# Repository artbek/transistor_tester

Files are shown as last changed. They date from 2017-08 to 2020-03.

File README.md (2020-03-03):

Transistor tester (BJT NPN pin identifier)
==========================================

The little gadget displays: `C`ollector, `b`ase, `E`mitter ... and an animation of slinky if no BJT can be detected.

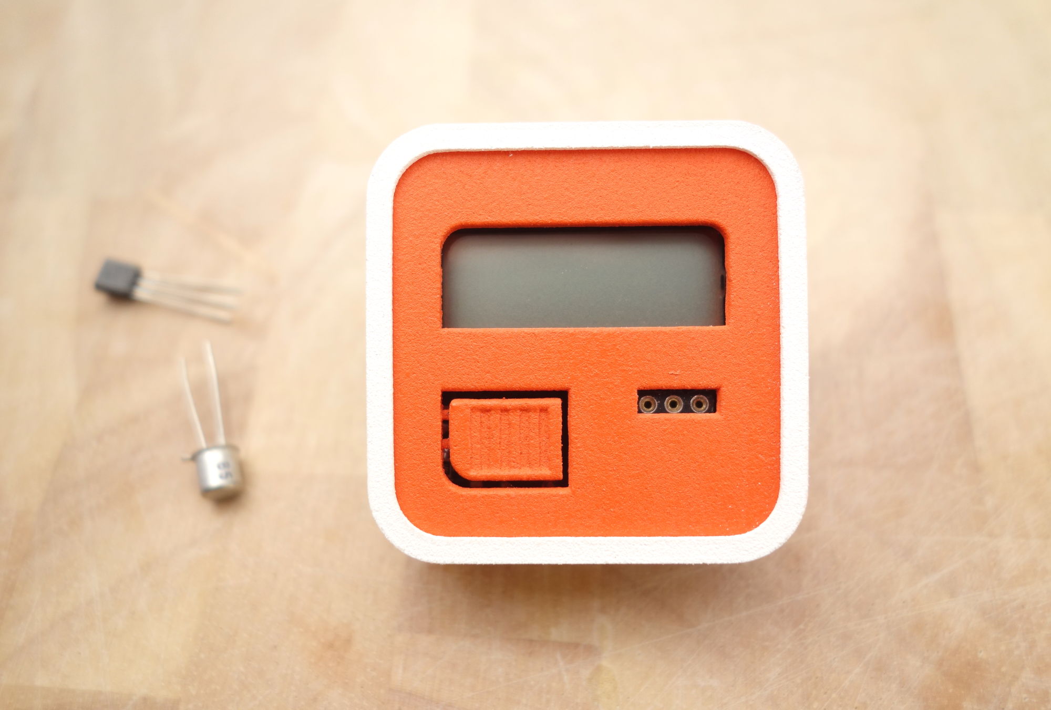
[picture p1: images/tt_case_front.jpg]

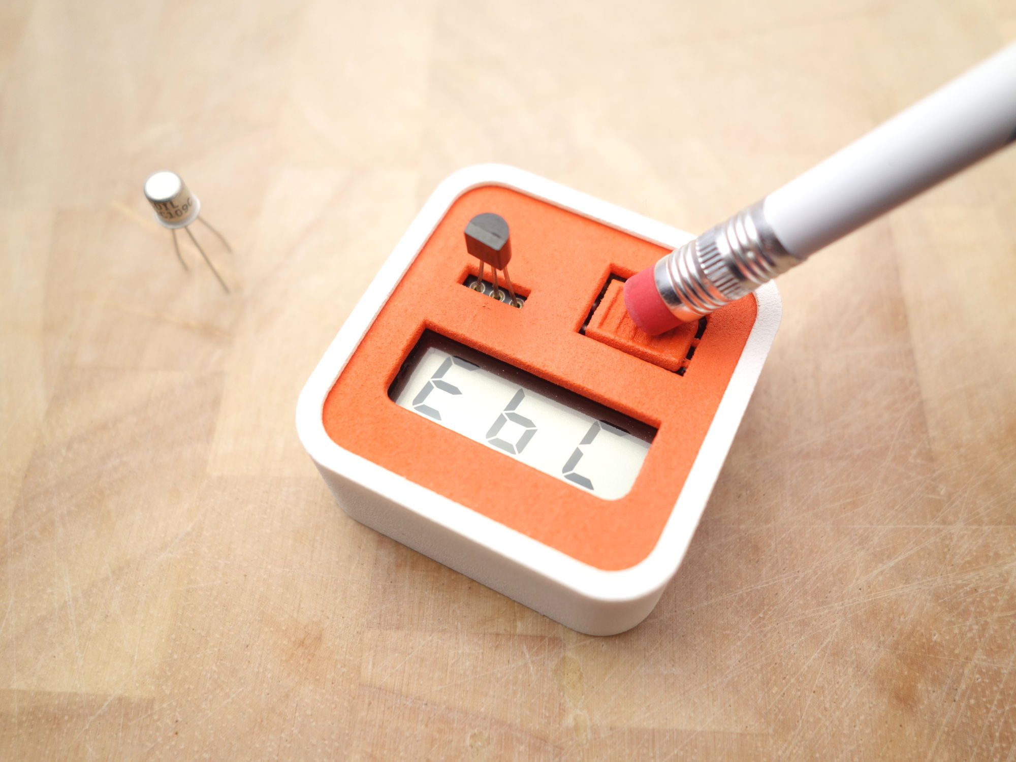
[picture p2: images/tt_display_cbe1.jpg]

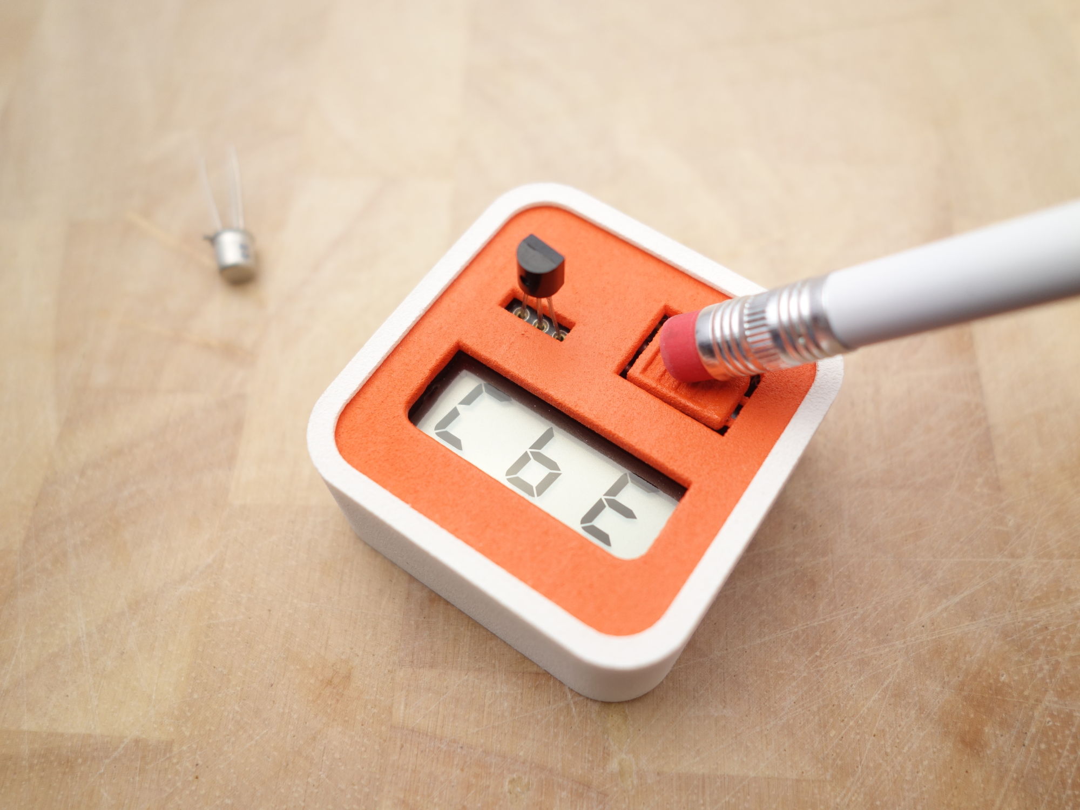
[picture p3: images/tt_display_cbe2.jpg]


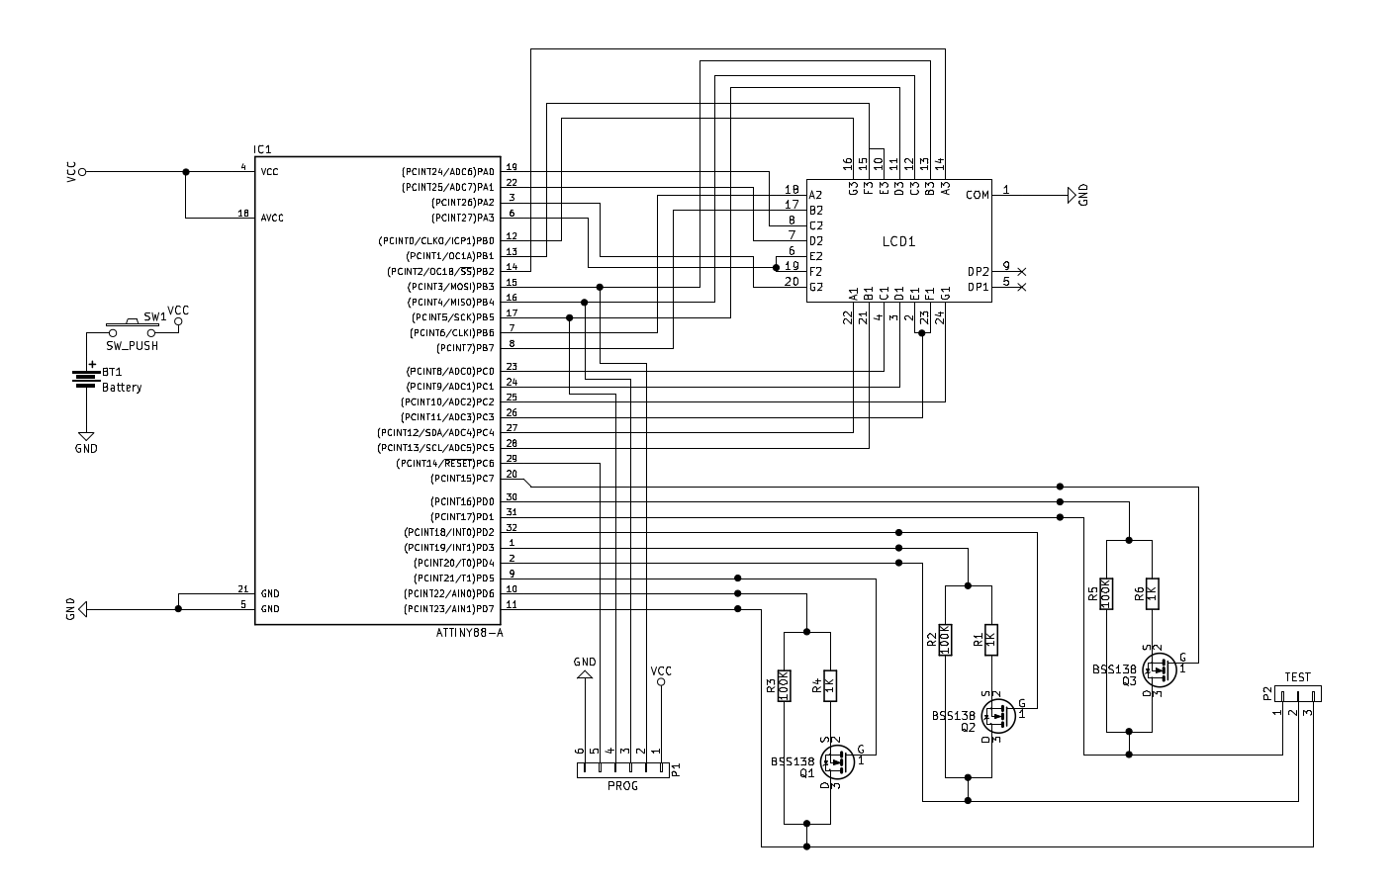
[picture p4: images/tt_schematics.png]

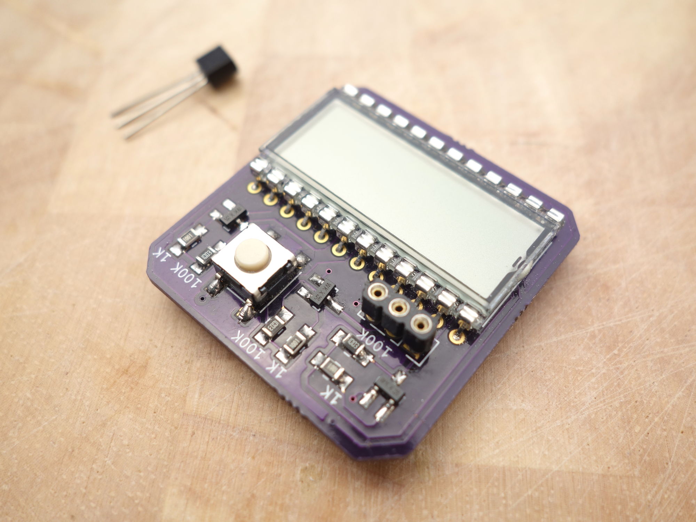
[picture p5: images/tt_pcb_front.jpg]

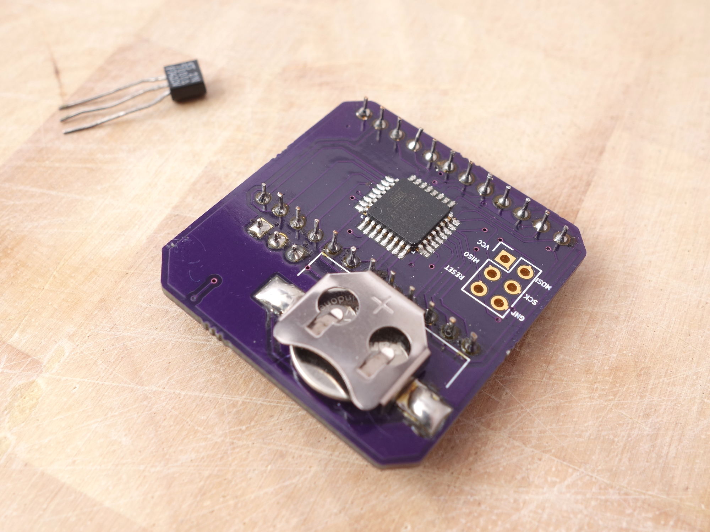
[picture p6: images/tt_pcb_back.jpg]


3D printed and spray-painted case.

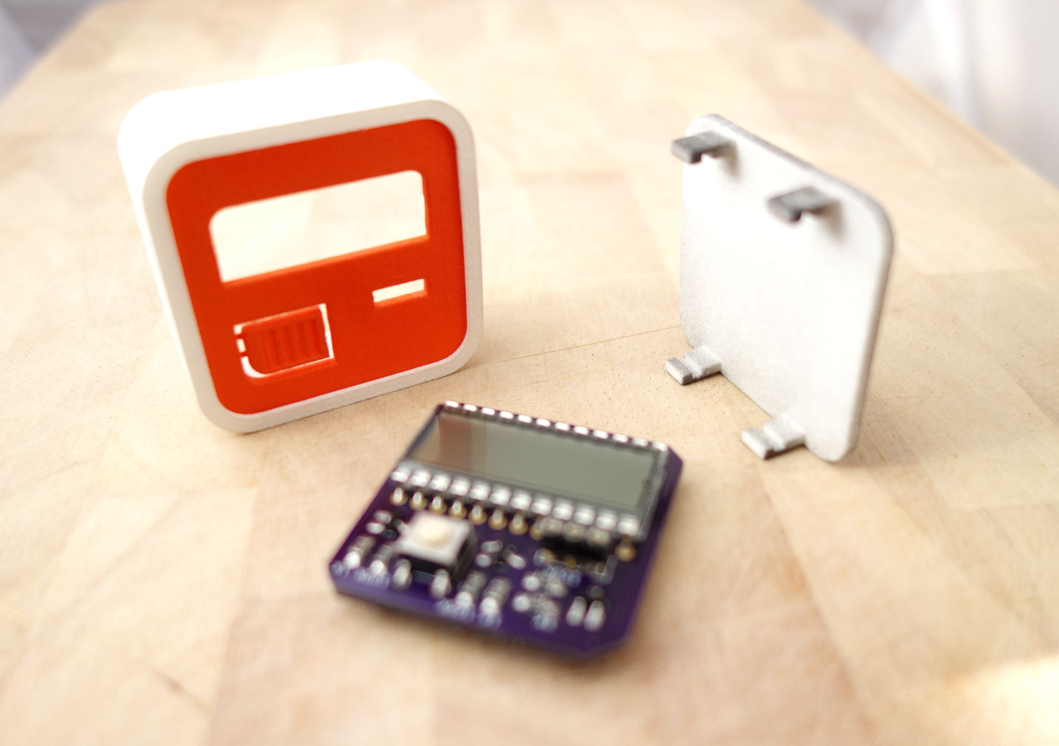
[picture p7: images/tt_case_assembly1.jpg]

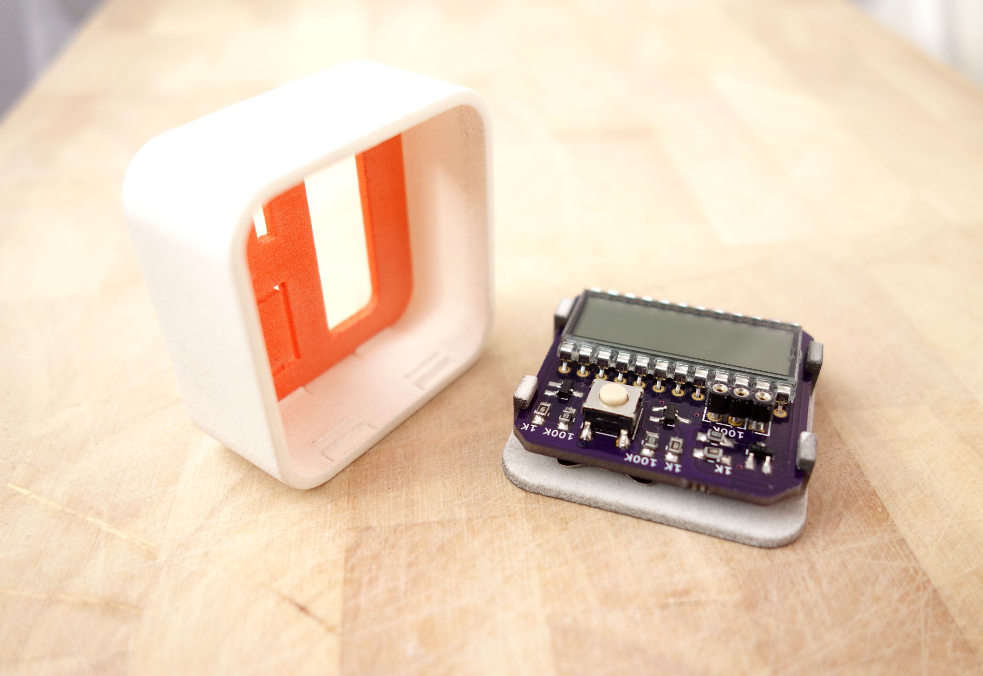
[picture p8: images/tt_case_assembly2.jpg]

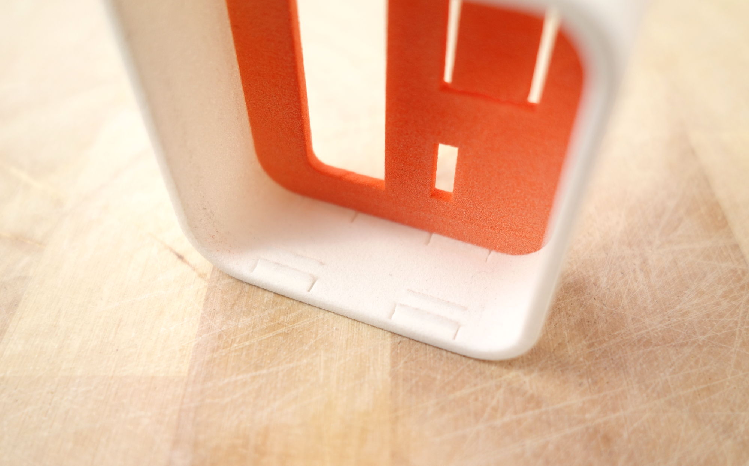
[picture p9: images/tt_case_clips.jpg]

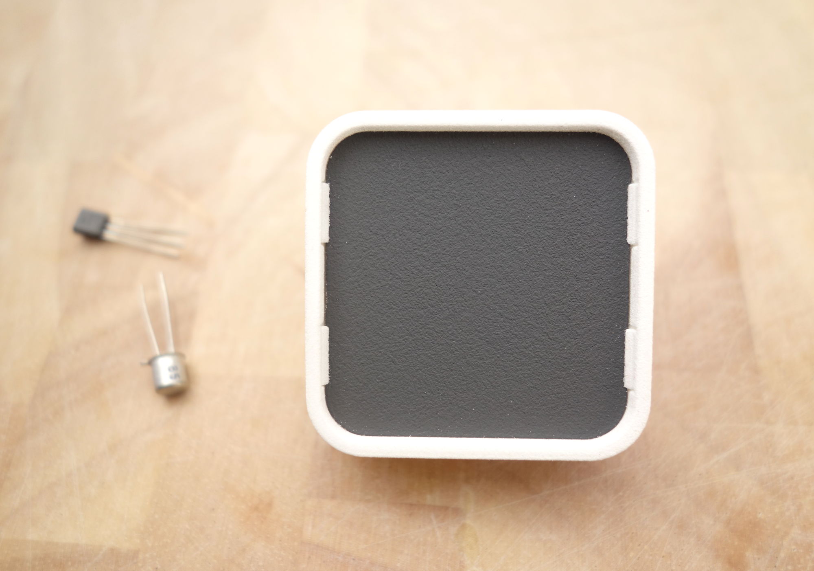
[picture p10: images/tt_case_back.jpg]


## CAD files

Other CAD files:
blender/transistor_tester.blend

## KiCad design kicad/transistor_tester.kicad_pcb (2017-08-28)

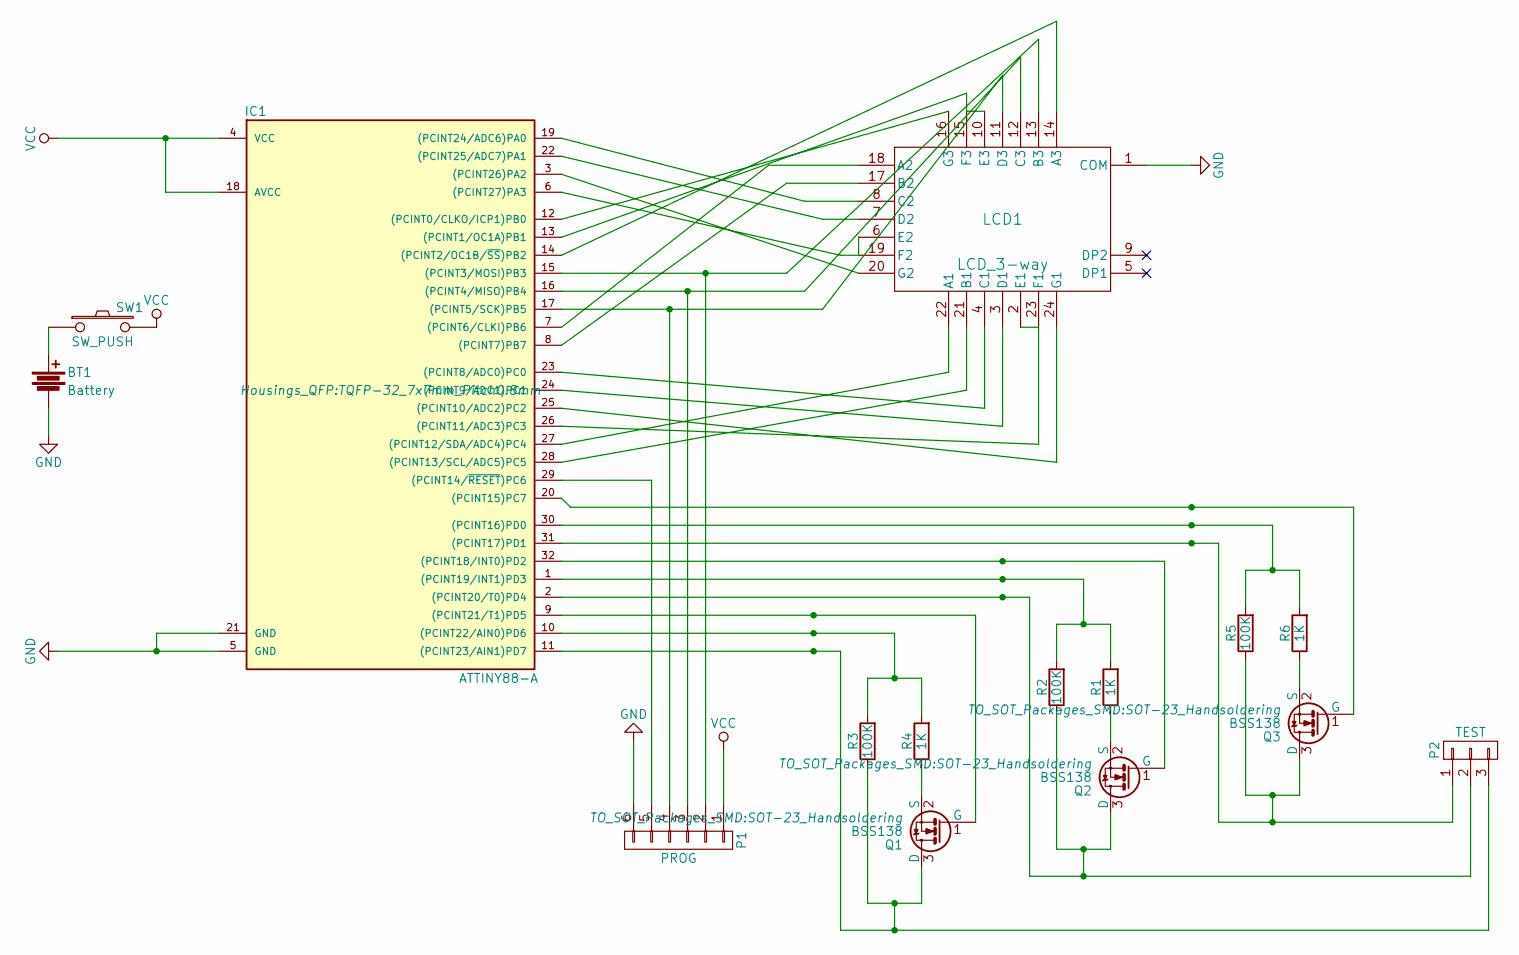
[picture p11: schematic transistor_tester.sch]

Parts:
BT1: Battery; cr1216
IC1: ATTINY88-A; TQFP-32_7x7mm_Pitch0.8mm
LCD1: LCD_3-way; LCD
P1: PROG; Pin_Header_Straight_2x03
P2: TEST; Pin_Header_Straight_1x03
Q1, Q2, Q3: BSS138; SOT-23_Handsoldering
R1, R4, R6: 1K; R_0805_HandSoldering
R2, R3, R5: 100K; R_0805_HandSoldering
SW1: SW_PUSH; SW_SPST_PTS645

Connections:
GND: BT1.2, IC1.5 (GND), IC1.21 (GND), LCD1.1 (COM), P1.6
unnamed: BT1.1, SW1.1
unnamed: IC1.1 ((PCINT19/INT1)PD3), R1.2, R2.2
unnamed: IC1.2 ((PCINT20/T0)PD4), P2.2, Q2.3 (D), R2.1
unnamed: IC1.3 ((PCINT26)PA2), LCD1.20 (G2)
unnamed: IC1.6 ((PCINT27)PA3), LCD1.6 (E2), LCD1.19 (F2)
unnamed: IC1.7 ((PCINT6/CLKI)PB6), LCD1.18 (A2)
unnamed: IC1.8 ((PCINT7)PB7), LCD1.17 (B2)
unnamed: IC1.9 ((PCINT21/T1)PD5), Q1.1 (G)
unnamed: IC1.10 ((PCINT22/AIN0)PD6), R3.2, R4.2
unnamed: IC1.11 ((PCINT23/AIN1)PD7), P2.3, Q1.3 (D), R3.1
unnamed: IC1.12 ((PCINT0/CLKO/ICP1)PB0), LCD1.16 (G3)
unnamed: IC1.13 ((PCINT1/OC1A)PB1), LCD1.10 (E3), LCD1.15 (F3)
unnamed: IC1.14 ((PCINT2/OC1B/~SS~)PB2), LCD1.14 (A3)
unnamed: IC1.15 ((PCINT3/MOSI)PB3), LCD1.13 (B3), P1.2
unnamed: IC1.16 ((PCINT4/MISO)PB4), LCD1.12 (C3), P1.3
unnamed: IC1.17 ((PCINT5/SCK)PB5), LCD1.11 (D3), P1.4
unnamed: IC1.19 ((PCINT24/ADC6)PA0), LCD1.8 (C2)
unnamed: IC1.20 ((PCINT15)PC7), Q3.1 (G)
unnamed: IC1.22 ((PCINT25/ADC7)PA1), LCD1.7 (D2)
unnamed: IC1.23 ((PCINT8/ADC0)PC0), LCD1.4 (C1)
unnamed: IC1.24 ((PCINT9/ADC1)PC1), LCD1.3 (D1)
unnamed: IC1.25 ((PCINT10/ADC2)PC2), LCD1.24 (G1)
unnamed: IC1.26 ((PCINT11/ADC3)PC3), LCD1.2 (E1), LCD1.23 (F1)
unnamed: IC1.27 ((PCINT12/SDA/ADC4)PC4), LCD1.22 (A1)
unnamed: IC1.28 ((PCINT13/SCL/ADC5)PC5), LCD1.21 (B1)
unnamed: IC1.29 ((PCINT14/~RESET~)PC6), P1.5
unnamed: IC1.30 ((PCINT16)PD0), R5.2, R6.2
unnamed: IC1.31 ((PCINT17)PD1), P2.1, Q3.3 (D), R5.1
unnamed: IC1.32 ((PCINT18/INT0)PD2), Q2.1 (G)
unnamed: Q1.2 (S), R4.1
unnamed: Q2.2 (S), R1.1
unnamed: Q3.2 (S), R6.1
VCC: IC1.4 (VCC), IC1.18 (AVCC), P1.1, SW1.2

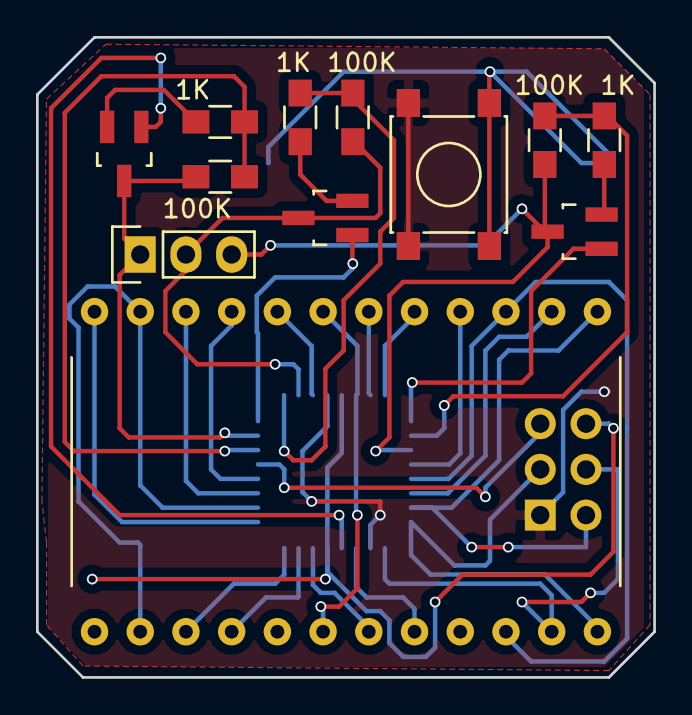
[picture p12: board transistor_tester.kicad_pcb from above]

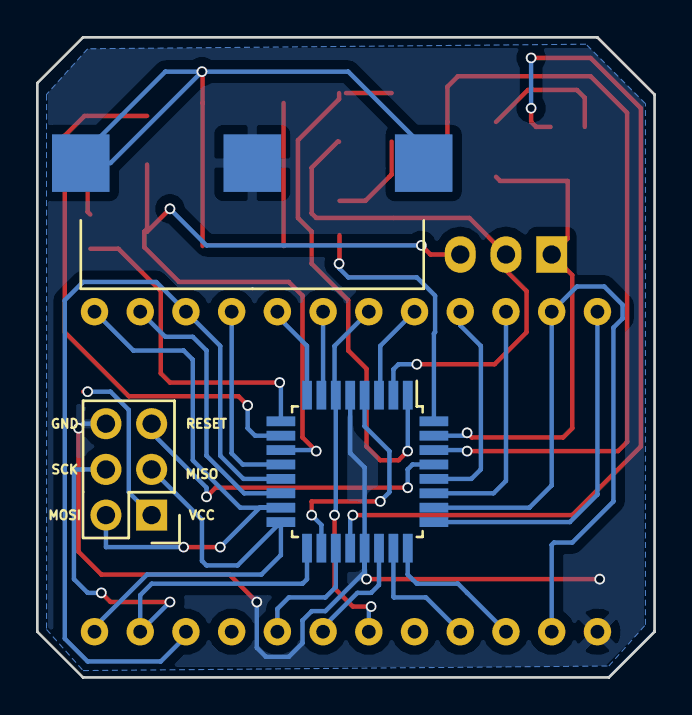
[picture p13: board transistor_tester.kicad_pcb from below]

Board: 2 copper layers, 34.3 x 35.6 mm, 15 parts (3 on the bottom side), 34 nets.

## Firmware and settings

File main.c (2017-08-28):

#include <avr/io.h>
#include <util/delay.h>

#ifndef uchar
#  define uchar  unsigned char
#endif

typedef enum { false, true } bool;

#define TEST_POINT_1 PD1
#define TEST_POINT_1_RESISTORS PD0
#define TEST_POINT_1_GATE PC7

#define TEST_POINT_2 PD4
#define TEST_POINT_2_RESISTORS PD3
#define TEST_POINT_2_GATE PD2

#define TEST_POINT_3 PD7
#define TEST_POINT_3_RESISTORS PD6
#define TEST_POINT_3_GATE PD5

#define SEG_A1 0
#define SEG_B1 1
#define SEG_C1 2
#define SEG_D1 3
#define SEG_E1 4
#define SEG_F1 5
#define SEG_G1 6

#define SEG_A2 7
#define SEG_B2 8
#define SEG_C2 9
#define SEG_D2 10
#define SEG_E2 11
#define SEG_F2 12
#define SEG_G2 13

#define SEG_A3 14
#define SEG_B3 15
#define SEG_C3 16
#define SEG_D3 17
#define SEG_E3 18
#define SEG_F3 19
#define SEG_G3 20




static uchar segments[21][2];

void init_segment_data()
{
	// SEGMENT 1
	segments[SEG_A1][0] = PC4; segments[SEG_A1][1] = 'C';
	segments[SEG_B1][0] = PC5; segments[SEG_B1][1] = 'C';
	segments[SEG_C1][0] = PC0; segments[SEG_C1][1] = 'C';
	segments[SEG_D1][0] = PC1; segments[SEG_D1][1] = 'C';
	segments[SEG_E1][0] = PC3; segments[SEG_E1][1] = 'C';
	segments[SEG_F1][0] = PC3; segments[SEG_F1][1] = 'C';
	segments[SEG_G1][0] = PC2; segments[SEG_G1][1] = 'C';

	// SEGMENT 2
	segments[SEG_A2][0] = PB6; segments[SEG_A2][1] = 'B';
	segments[SEG_B2][0] = PB7; segments[SEG_B2][1] = 'B';
	segments[SEG_C2][0] = PA0; segments[SEG_C2][1] = 'A';
	segments[SEG_D2][0] = PA1; segments[SEG_D2][1] = 'A';
	segments[SEG_E2][0] = PA3; segments[SEG_E2][1] = 'A';
	segments[SEG_F2][0] = PA3; segments[SEG_F2][1] = 'A';
	segments[SEG_G2][0] = PA2; segments[SEG_G2][1] = 'A';

	// SEGMENT 3
	segments[SEG_A3][0] = PB2; segments[SEG_A3][1] = 'B';
	segments[SEG_B3][0] = PB3; segments[SEG_B3][1] = 'B';
	segments[SEG_C3][0] = PB4; segments[SEG_C3][1] = 'B';
	segments[SEG_D3][0] = PB5; segments[SEG_D3][1] = 'B';
	segments[SEG_E3][0] = PB1; segments[SEG_E3][1] = 'B';
	segments[SEG_F3][0] = PB1; segments[SEG_F3][1] = 'B';
	segments[SEG_G3][0] = PB0; segments[SEG_G3][1] = 'B';
}

void led_clear()
{
	PORTA = 0x00;
	PORTB = 0x00;
	PORTC = 0x00;
}

void led_on(uchar segment)
{
	uchar ddr_value = _BV(segments[segment][0]); // set to output
	uchar port_value = _BV(segments[segment][0]); // set on

	if (segments[segment][1] == 'A') {
		DDRA |= ddr_value;
		PORTA |= port_value;
	} else if (segments[segment][1] == 'B') {
		DDRB |= ddr_value;
		PORTB |= port_value;
	} else if (segments[segment][1] == 'C') {
		DDRC |= ddr_value;
		PORTC |= port_value;
	}
}

void led_off(uchar segment)
{
	uchar ddr_value = _BV(segments[segment][0]); // set to output
	uchar port_value = _BV(segments[segment][0]); // set on

	if (segments[segment][1] == 'A') {
		DDRA |= ddr_value;
		PORTA &= ~port_value;
	} else if (segments[segment][1] == 'B') {
		DDRB |= ddr_value;
		PORTB &= ~port_value;
	} else if (segments[segment][1] == 'C') {
		DDRC |= ddr_value;
		PORTC &= ~port_value;
	}
}


void segments_all_on()
{
	led_on(SEG_A1); led_on(SEG_B1); led_on(SEG_C1); led_on(SEG_D1); led_on(SEG_E1); led_on(SEG_G1);
	led_on(SEG_A2); led_on(SEG_B2); led_on(SEG_C2); led_on(SEG_D2); led_on(SEG_E2); led_on(SEG_G2);
	led_on(SEG_A3); led_on(SEG_B3); led_on(SEG_C3); led_on(SEG_D3); led_on(SEG_E3); led_on(SEG_G3);
}

void segments_all_off()
{
	led_off(SEG_A1); led_off(SEG_B1); led_off(SEG_C1); led_off(SEG_D1); led_off(SEG_E1); led_off(SEG_G1);
	led_off(SEG_A2); led_off(SEG_B2); led_off(SEG_C2); led_off(SEG_D2); led_off(SEG_E2); led_off(SEG_G2);
	led_off(SEG_A3); led_off(SEG_B3); led_off(SEG_C3); led_off(SEG_D3); led_off(SEG_E3); led_off(SEG_G3);
}


bool is_base(int base, int collector, int emmiter)
{
	// Reset after previous tests ...
	PORTD |= _BV(TEST_POINT_1_RESISTORS);
	PORTD |= _BV(TEST_POINT_2_RESISTORS);
	PORTD |= _BV(TEST_POINT_3_RESISTORS);

	DDRD &= ~_BV(base); // set to input
	PORTD |= _BV(base); // set high

	_delay_ms(10);

	DDRD |= _BV(collector); // set to output
	DDRD |= _BV(emmiter); // set to output
	PORTD &= ~_BV(collector); // set low
	PORTD &= ~_BV(emmiter); // set low

	_delay_ms(10);

	if (bit_is_clear(PIND, base)) { return true; }

	return false;
}


int emitter;
int collector;
int base;

void detect_collector(int base_testpoint_number, int a_testpoint_number, int b_testpoint_number)
{
	/* BASE */

	int base_testpoint_pin;
	bool base_ready = false;
	if (base_testpoint_number == 1) {
		base_testpoint_pin = TEST_POINT_1;
		base_ready = true;
	} else if (base_testpoint_number == 2) {
		base_testpoint_pin = TEST_POINT_2;
		base_ready = true;
	} else if (base_testpoint_number == 3) {
		base_testpoint_pin = TEST_POINT_1;
		base_ready = true;
	}

	if (base_ready) {
		DDRD &= ~_BV(base_testpoint_pin); PORTD |= _BV(base_testpoint_pin); // IN high
	} else {
		return;
	}


	/* A */

	bool a_testpoint_ready = false;
	if (a_testpoint_number == 1) {
		DDRC |= _BV(TEST_POINT_1_GATE); PORTC |= _BV(TEST_POINT_1_GATE); // OUT high
		DDRD |= _BV(TEST_POINT_1_RESISTORS); PORTD |= _BV(TEST_POINT_1_RESISTORS); // OUT high ***
		DDRD &= ~_BV(TEST_POINT_1); PORTD &= ~_BV(TEST_POINT_1); // IN low
		a_testpoint_ready = true;
	} else if (a_testpoint_number == 2) {
		DDRD |= _BV(TEST_POINT_2_GATE); PORTD |= _BV(TEST_POINT_2_GATE); // OUT high
		DDRD |= _BV(TEST_POINT_2_RESISTORS); PORTD |= _BV(TEST_POINT_2_RESISTORS); // OUT high ***
		DDRD &= ~_BV(TEST_POINT_2); PORTD &= ~_BV(TEST_POINT_2); // IN low
		a_testpoint_ready = true;
	} else if (a_testpoint_number == 3) {
		DDRD |= _BV(TEST_POINT_3_GATE); PORTD |= _BV(TEST_POINT_3_GATE); // OUT high
		DDRD |= _BV(TEST_POINT_3_RESISTORS); PORTD |= _BV(TEST_POINT_3_RESISTORS); // OUT high ***
		DDRD &= ~_BV(TEST_POINT_3); PORTD &= ~_BV(TEST_POINT_3); // IN low
		a_testpoint_ready = true;
	}


	/* B */

	int b_testpoint_pin;
	bool b_testpoint_ready = false;
	if (b_testpoint_number == 1) {
		b_testpoint_pin = TEST_POINT_1;
		DDRC |= _BV(TEST_POINT_1_GATE); PORTC |= _BV(TEST_POINT_1_GATE); // OUT high
		DDRD |= _BV(TEST_POINT_1_RESISTORS); PORTD &= ~_BV(TEST_POINT_1_RESISTORS); // OUT low ***
		DDRD &= ~_BV(TEST_POINT_1); PORTD &= ~_BV(TEST_POINT_1); // IN low
		b_testpoint_ready = true;
	} else if (b_testpoint_number == 2) {
		b_testpoint_pin = TEST_POINT_2;
		DDRD |= _BV(TEST_POINT_2_GATE); PORTD |= _BV(TEST_POINT_2_GATE); // OUT high
		DDRD |= _BV(TEST_POINT_2_RESISTORS); PORTD &= ~_BV(TEST_POINT_2_RESISTORS); // OUT low ***
		DDRD &= ~_BV(TEST_POINT_2); PORTD &= ~_BV(TEST_POINT_2); // IN low
		b_testpoint_ready = true;
	} else if (b_testpoint_number == 3) {
		b_testpoint_pin = TEST_POINT_3;
		DDRD |= _BV(TEST_POINT_3_GATE); PORTD |= _BV(TEST_POINT_3_GATE); // OUT high
		DDRD |= _BV(TEST_POINT_3_RESISTORS); PORTD &= ~_BV(TEST_POINT_3_RESISTORS); // OUT low ***
		DDRD &= ~_BV(TEST_POINT_3); PORTD &= ~_BV(TEST_POINT_3); // IN low
		b_testpoint_ready = true;
	}


	if (a_testpoint_ready && b_testpoint_ready) {
		if (bit_is_set(PIND, b_testpoint_pin)) {
			emitter = b_testpoint_number;
			collector = a_testpoint_number;
		}
	}
}


bool identify_leads()
{
	emitter = 0;
	collector = 0;
	base = 0;

	if (is_base(TEST_POINT_1, TEST_POINT_2, TEST_POINT_3)) {
		base = 1;
		detect_collector(base, 2, 3);
		if (emitter == 0 || collector == 0) detect_collector(base, 3, 2);
	} else if (is_base(TEST_POINT_2, TEST_POINT_1, TEST_POINT_3)) {
		base = 2;
		detect_collector(base, 1, 3);
		if (emitter == 0 || collector == 0) detect_collector(base, 3, 1);
	} else if (is_base(TEST_POINT_3, TEST_POINT_1, TEST_POINT_2)) {
		base = 3;
		detect_collector(base, 1, 2);
		if (emitter == 0 || collector == 0) detect_collector(base, 2, 1);
	}

	if (emitter > 0 && collector > 0 && base > 0) {
		return true;
	} else {
		return false;
	}
}


void led_on_b(int segment_number)
{
	if (segment_number == 1) {
		led_on(SEG_E1); led_on(SEG_G1); led_on(SEG_D1); led_on(SEG_C1);
	} else if (segment_number == 2) {
		led_on(SEG_E2); led_on(SEG_G2); led_on(SEG_D2); led_on(SEG_C2);
	} else if (segment_number == 3) {
		led_on(SEG_E3); led_on(SEG_G3); led_on(SEG_D3); led_on(SEG_C3);
	}
}


void led_on_c(int segment_number)
{
	if (segment_number == 1) {
		led_on(SEG_A1); led_on(SEG_D1); led_on(SEG_E1);
	} else if (segment_number == 2) {
		led_on(SEG_A2); led_on(SEG_D2); led_on(SEG_E2);
	} else if (segment_number == 3) {
		led_on(SEG_A3); led_on(SEG_D3); led_on(SEG_E3);
	}
}


void led_on_e(int segment_number)
{
	if (segment_number == 1) {
		led_on(SEG_A1); led_on(SEG_D1); led_on(SEG_E1); led_on(SEG_G1);
	} else if (segment_number == 2) {
		led_on(SEG_A2); led_on(SEG_D2); led_on(SEG_E2); led_on(SEG_G2);
	} else if (segment_number == 3) {
		led_on(SEG_A3); led_on(SEG_D3); led_on(SEG_E3); led_on(SEG_G3);
	}
}



/*** MAIN ***/

int __attribute__((noreturn)) main(void)
{
	init_segment_data();
	segments_all_off();

	int wait_time = 30;

	while (1) {
		if (identify_leads()) {
			segments_all_off();
			_delay_ms(10);
			led_on_b(base);
			led_on_c(collector);
			led_on_e(emitter);
			_delay_ms(1000);

		} else {
			led_on(SEG_A1); _delay_ms(wait_time);
			led_off(SEG_D1); _delay_ms(wait_time);

			led_on(SEG_A2); _delay_ms(wait_time);
			led_off(SEG_E1); _delay_ms(wait_time);

			led_on(SEG_A3); _delay_ms(wait_time);
			led_off(SEG_A1); _delay_ms(wait_time);

			led_on(SEG_B3); _delay_ms(wait_time);
			led_off(SEG_A2); _delay_ms(wait_time);

			led_on(SEG_C3); _delay_ms(wait_time);
			led_off(SEG_A3); _delay_ms(wait_time);

			led_on(SEG_D3); _delay_ms(wait_time);
			led_off(SEG_B3); _delay_ms(wait_time);

			led_on(SEG_D2); _delay_ms(wait_time);
			led_off(SEG_C3); _delay_ms(wait_time);

			led_on(SEG_D1); _delay_ms(wait_time);
			led_off(SEG_D3); _delay_ms(wait_time);

			led_on(SEG_E1); _delay_ms(wait_time);
			led_off(SEG_D2); _delay_ms(wait_time);
		}
	}
}
